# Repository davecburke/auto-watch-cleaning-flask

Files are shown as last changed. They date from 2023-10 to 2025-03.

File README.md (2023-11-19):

# auto-watch-cleaning-flask

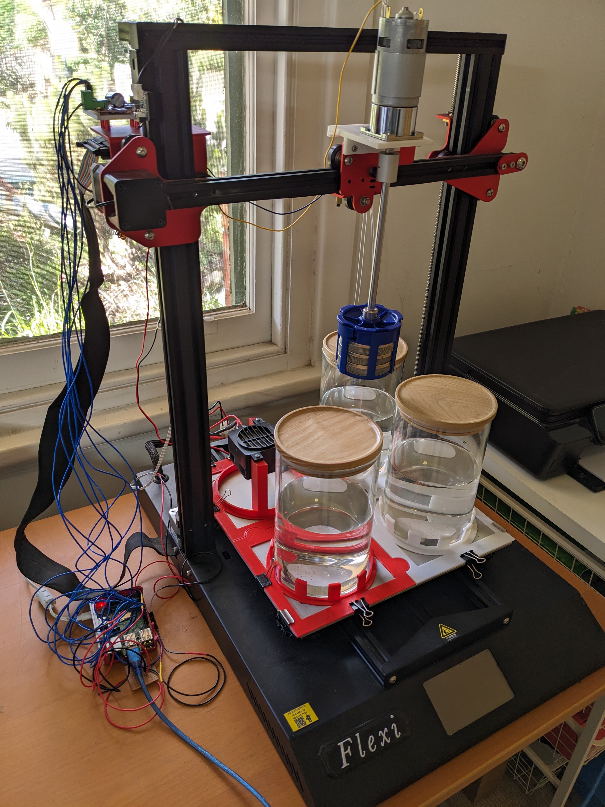
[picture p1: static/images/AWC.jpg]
AWC Auto Watch Cleaning Machine


Watch cleaning machines make the cleaning of mechanical watches both convenient and very effective but they can be expensive with most manual machines starting at around $1000 AUD and automatic machines starting at around $8,000 AUD. This is a big expense for a hobbiest like me.

It dawned on me that a 3D printer could be converted into a watch cleaning machine by replacing the hotend on the X axis with a spinning motor. How hard could it be, right!

## Specifications
- Fully automatic
- 1 x Cleaning Chamber
- 2 x Rinse Chamber
- 1 x Drying Chamber
NB: I've decided to make it easier for myself so I purchases the Elma SE Basket Complete and the Elma Basket Holder for RM/SE. You could of course rig up your own basket system on the cheap

## Features
The cleaning stage and the two rinse stages consist of two phases, the wash/rinse phase and the spin phase to expel liquid. The drying stage only has a spin phase.  All features are configured via a configuration file. These include:
- Setting the duration of each phase of the clean
- Setting the motor speed for each phase of the clean
- Setting the motor action for each phase of the clean. These are forward, backward and agitate (a user configured combination of forward and backward movements)

For detail of the full build, see my [instructable](https://www.instructables.com/3D-Printer-Conversion-to-Automatic-Watch-Cleaning-/)

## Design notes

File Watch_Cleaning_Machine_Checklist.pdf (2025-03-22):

## Watch Cleaning Machine Checklist

### Machine Cleaning Stages

Stage | Jar | Fluid | Action | RPM | Time | Notes
Cleaning | 1 | Shellite or Naphtha | Agitate + Spin (F/B) | 400-600 | 3-5 min | Removes oils & dirt
Rinse 1 | 2 | Clean Shellite | Slow Spin (F/B alt) | 400-600 | 2-3 min | Clears residual cleaner
Rinse 2 | 3 | Ultra-clean Shellite or
| | 99.9% IPA | Slow Spin (F/B alt) | 400-600 | 2-3 min | Final solvent rinse
Drying | - | - | Spin + Optional Heat | 800-1200 | 15-30 sec | No shellac-sensitive parts!

### Solvent Notes

- Shellite = Australian lighter fluid. Safe for delicate parts when used manually.
- 99.9% IPA = Optional final rinse. Avoid if unsure of purity.
- Avoid using water in this workflow - may damage shellac or cause rust.

### Manual Cleaning (Do Separately)

### - Pallet Fork & Balance Assembly: - Dip manually in Shellite (30-60 sec) - No brushing or ultrasonic - Blow-dry with air puffer - Avoid IPA and water

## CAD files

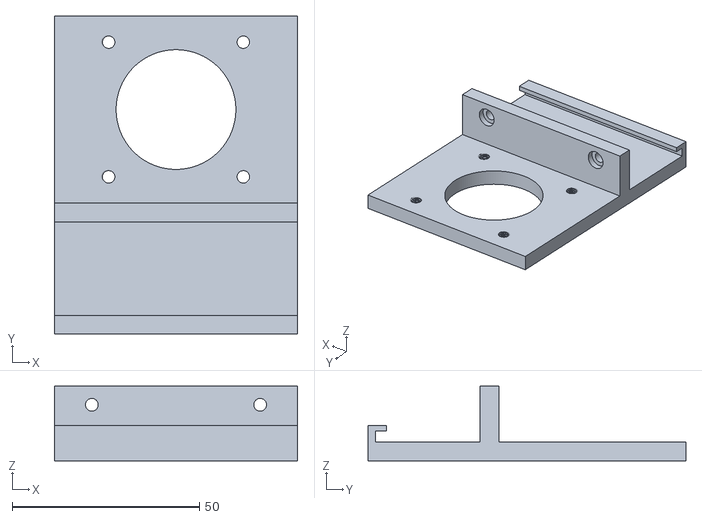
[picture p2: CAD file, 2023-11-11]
Freecad/WatchCleaning/Motor_Mount/Motor_Mount-Complete.stl
65.0 x 85.0 x 20.0

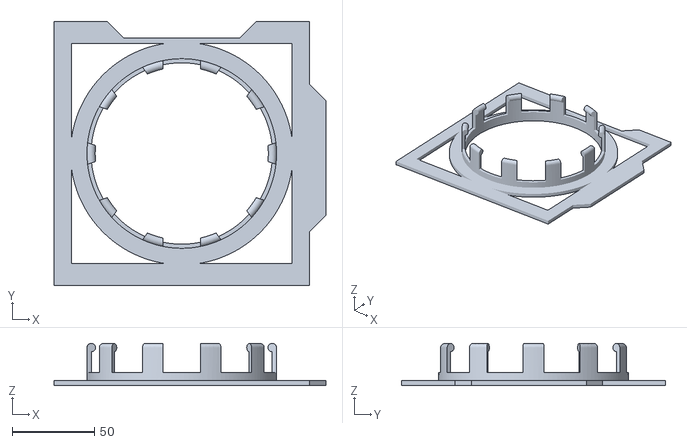
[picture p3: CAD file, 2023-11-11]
Freecad/WatchCleaning/Jar_Holders/Jar_Holders-Body.stl
165.0 x 160.0 x 25.5

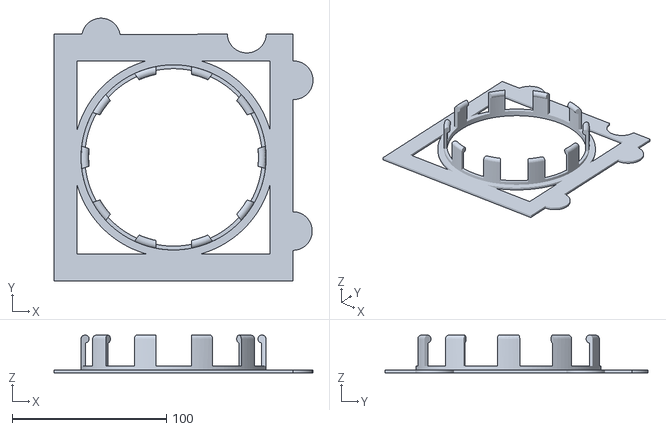
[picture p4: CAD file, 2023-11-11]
Freecad/WatchCleaning/Jar_Holders/Version2/JarHoldersV2_Split-Slice.FL.stl
167.9 x 170.2 x 24.5

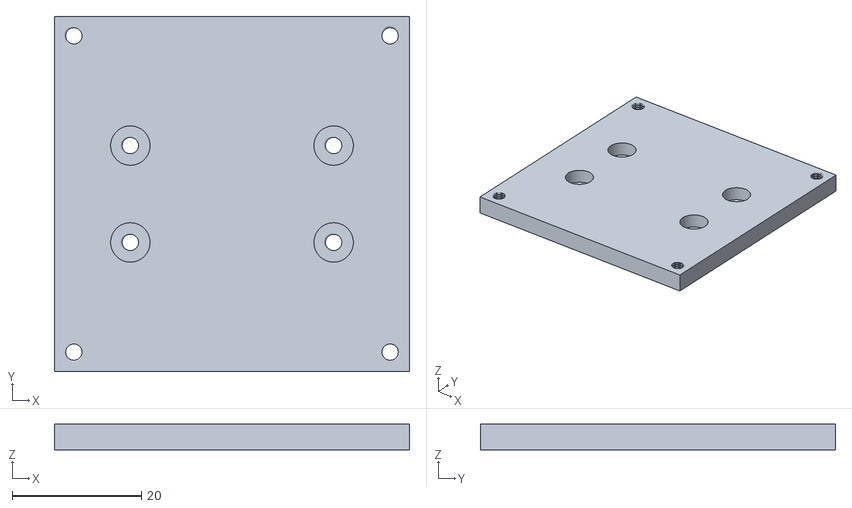
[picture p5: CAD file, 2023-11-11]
Freecad/WatchCleaning/Motor_Controller_Mount/Motor_Controller_Mount-Body2.stl
55.0 x 55.0 x 4.00

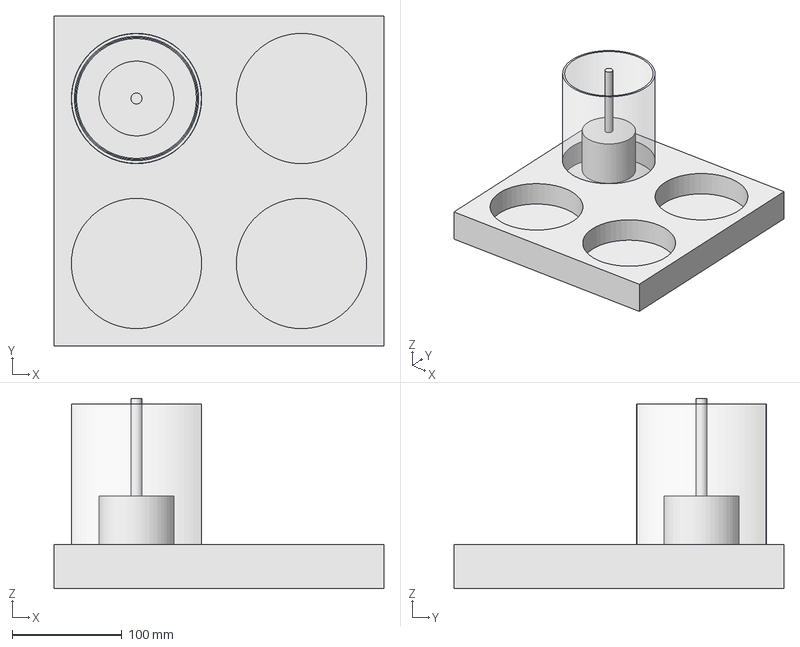
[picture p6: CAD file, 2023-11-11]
Freecad/WatchCleaning/WatchCleaning_v1.FCStd
300.0 x 300.0 x 173.0 mm
Jar
Basket
Base

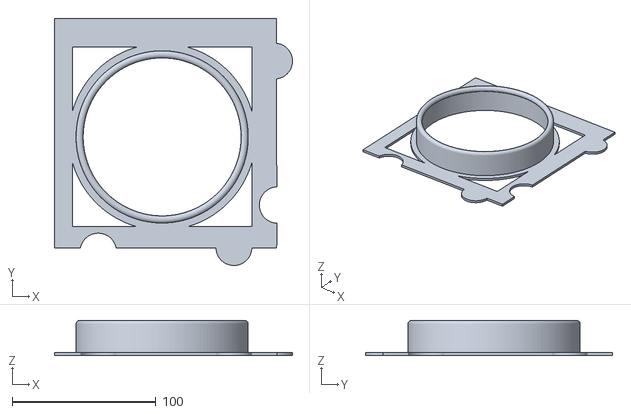
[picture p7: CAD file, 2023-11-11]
Freecad/WatchCleaning/Jar_Holders/Version2/JarHoldersV2_Split-Slice.BL.stl
165.8 x 172.1 x 24.5

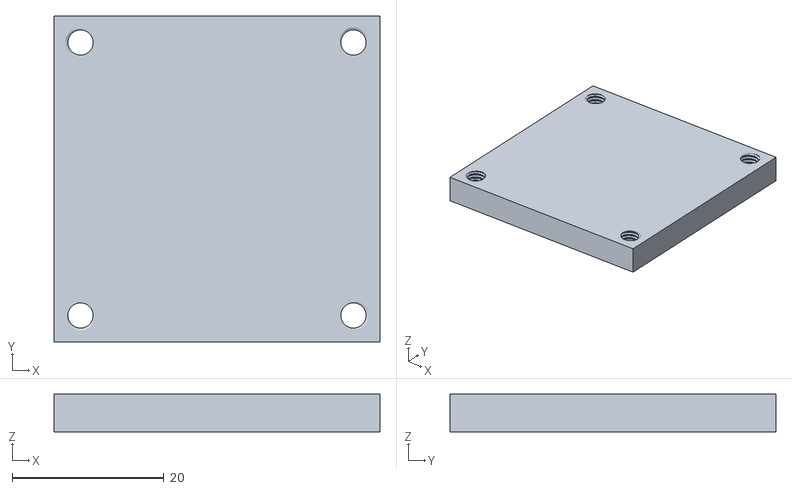
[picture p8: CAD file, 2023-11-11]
Freecad/WatchCleaning/Motor_Mount/Motor_Mount-Mount.stl
43.0 x 43.0 x 5.00

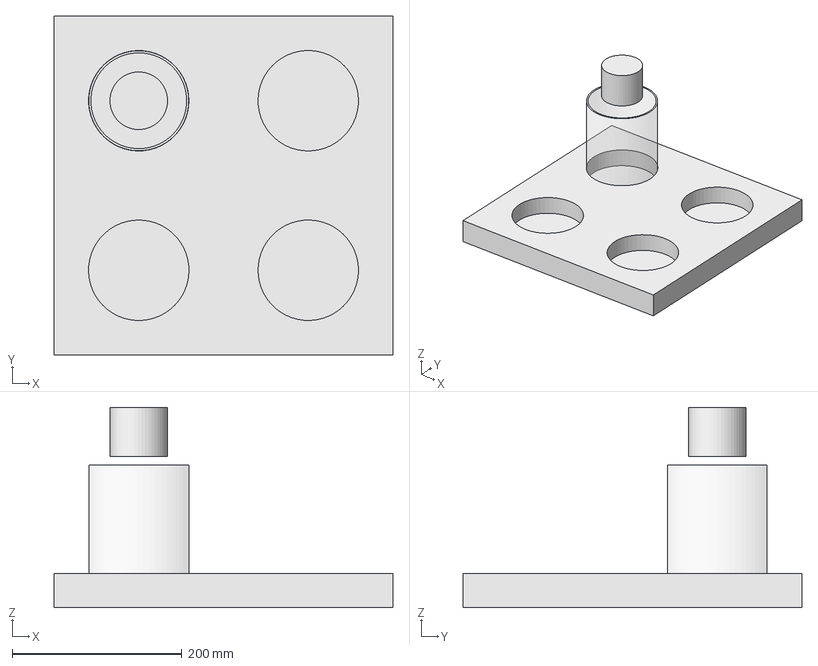
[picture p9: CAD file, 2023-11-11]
Freecad/WatchCleaning/WatchCleaning.FCStd
400.0 x 400.0 x 236.0 mm
Jar
Basket
Base

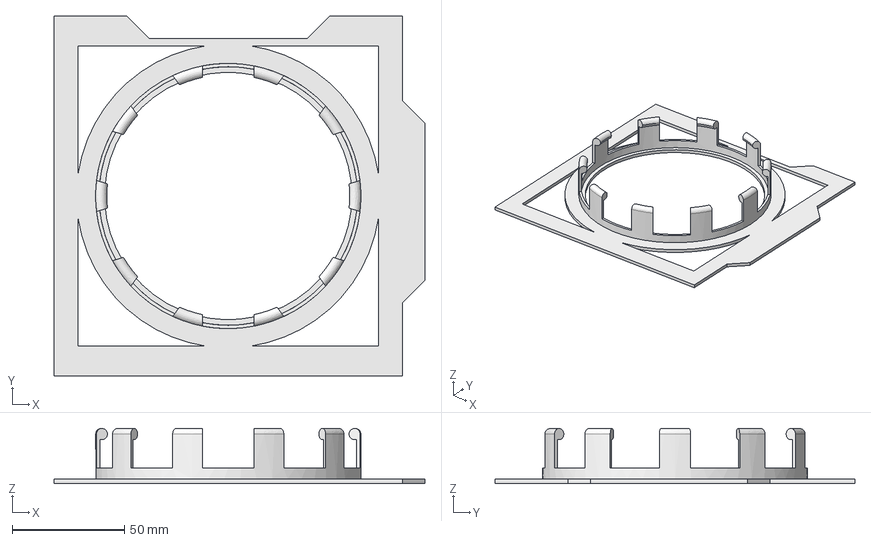
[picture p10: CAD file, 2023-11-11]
Freecad/WatchCleaning/Jar_Holders/Jar_Holders3.FCStd
165.0 x 160.0 x 24.5 mm

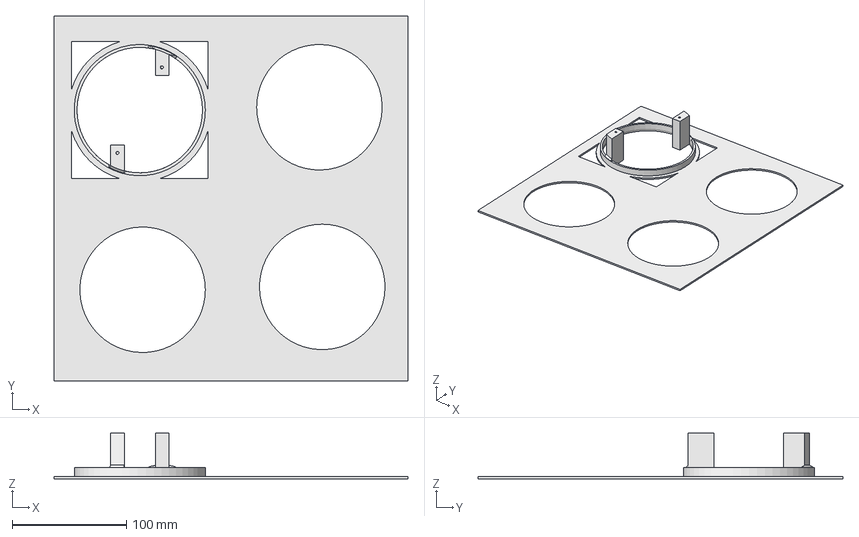
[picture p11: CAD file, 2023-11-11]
Freecad/WatchCleaning/Jar_Holders/Version2/JarHoldersV5_Heater_PreSplit.FCStd
310.0 x 320.0 x 40.0 mm

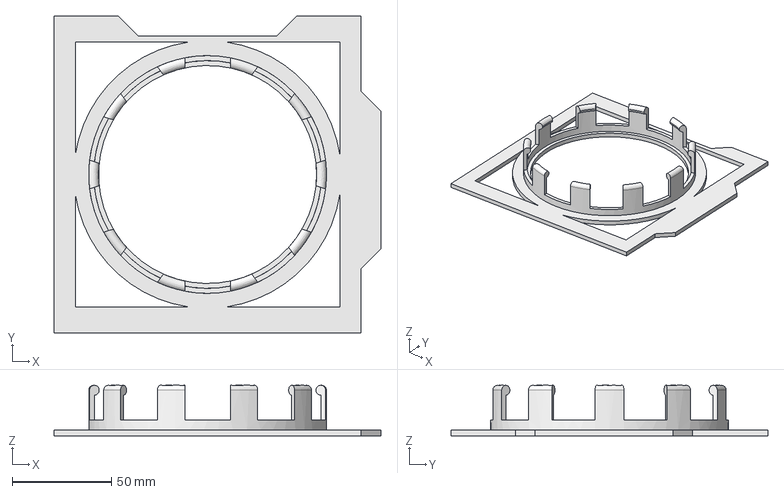
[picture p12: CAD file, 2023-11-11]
Freecad/WatchCleaning/Jar_Holders/Jar_Holders2.FCStd
165.0 x 160.0 x 25.5 mm

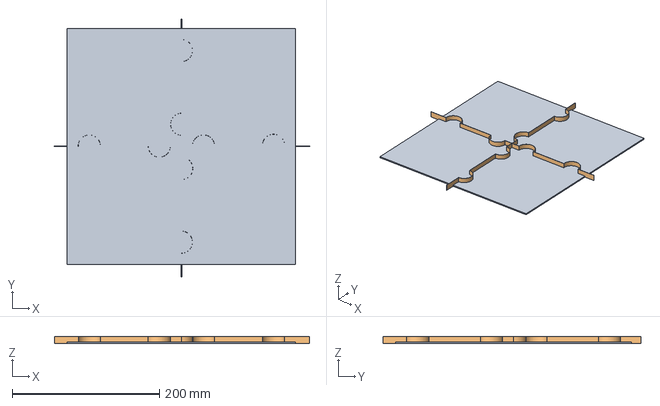
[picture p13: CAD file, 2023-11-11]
Freecad/WatchCleaning/Jar_Holders/Version2/JarHoldersV2_base.FCStd
346.0 x 350.0 x 10.0 mm
BuildPlate
Cutter

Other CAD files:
Freecad/WatchCleaning/Jar_Holders/Jar_Holders.FCStd
Freecad/WatchCleaning/Motor_Controller_Mount/Motor_Controller_Mount.FCStd
Freecad/WatchCleaning/Motor_Controller_Mount/Motor_Controller_Mount-Body.stl
Freecad/WatchCleaning/Motor_Mount/Motor_Mount.FCStd
Freecad/WatchCleaning/Motor_Controller_Mount/Motor_Controller_Mount-Body3.stl
Freecad/WatchCleaning/Jar_Holders/Jar_Holders2-Body.stl
Freecad/WatchCleaning/Jar_Holders/Jar_Holders3-Body.stl
Freecad/WatchCleaning/Jar_Holders/Version2/JarHoldersV2.FCStd
Freecad/WatchCleaning/Jar_Holders/Version2/JarHoldersV2_PreSplit.FCStd
Freecad/WatchCleaning/Jar_Holders/Version2/JarHoldersV2_Split-Slice.BR.stl
Freecad/WatchCleaning/Jar_Holders/Version2/JarHoldersV2_Split-Slice.FR.stl
Freecad/WatchCleaning/Jar_Holders/Version2/JarHoldersV2_Split.FCStd
Freecad/WatchCleaning/Jar_Holders/Version2/JarHoldersV6_Heater_PreSplit-BL.stl
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

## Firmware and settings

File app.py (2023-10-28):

from flask import Flask, render_template, request
# from flask_cors import CORS
import atexit
from config import Config 
from printer import Printer
from cleaning import Cleaning

app = Flask(__name__)
# CORS(app, resources={r'/*': {'origins': '*'}})
app_config = Config('app.config')
print(app_config.dry_cycle.dry.motor_setting.speed)
app_printer = Printer();
app_cleaning = Cleaning()
def startCleaningProcess():
    if app_printer.prepare_printer():
        app_cleaning.clean()

def restartFirware():
    return app_printer.app_moonraker_util.firmware_restart()

def homePrinter(): 
    return app_printer.home_printer()
          
    
@app.route("/", methods=['GET', 'POST'])
def index():
    templateData = {}
    cleaning_status = 'Off'
    firmware_restart_status = ''
    firmware_state = ''
    firmware_message = ''
    homing_state = ''
    if request.method == 'POST':
        if request.form.get('start') == 'Start Cleaning':
            cleaning_status = 'Start'
            startCleaningProcess()
        if request.form.get('restart_firmware') == 'Restart Firmware':
            res = restartFirware();
            print(res)
            firmware_restart_status = 'Starting'
            while True:
                react_dict = app_printer.app_moonraker_util.server_get("/printer/info")
                if('result' in react_dict):
                    break
        if request.form.get('home') == 'Home':
            homing_state = 'Homing'
            while True:
                react_dict = homePrinter()
                if(app_printer.app_moonraker_util.is_printer_homed):
                    break
    react_dict = app_printer.app_moonraker_util.server_get("/printer/info")
    if('result' in react_dict):
        firmware_state = react_dict['result']['state']
        firmware_message = react_dict['result']['state_message']

    if(app_printer.app_moonraker_util.is_printer_homed):
        homing_state = 'Homed'
    else: 
        homing_state = 'Not Homed'        
    templateData = {'firmware_state': firmware_state, 'firmware_message': firmware_message, 'cleaning_status': cleaning_status, 'restart_status': firmware_restart_status, 'homing_state': homing_state}
    print(templateData)
    return render_template('index.html', **templateData)

def exit_handler():
    app_cleaning.app_motor.clean_up()
atexit.register(exit_handler) 

if __name__ == '__main__':
    app.run(host='0.0.0.0')

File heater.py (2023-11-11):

import RPi.GPIO as GPIO
class Heater():
    def __init__(self, in1, in2, en, element):
        print(in1)
        print(in2)
        print(en)
        self.in1 = in1;
        self.in2 = in2;
        self.en = en;
        self.element = element
        GPIO.setmode(GPIO.BOARD)
        GPIO.setup(in1, GPIO.OUT)
        GPIO.setup(in2, GPIO.OUT)
        GPIO.setup(en, GPIO.OUT)
        GPIO.setup(element, GPIO.OUT)
        # self.pi_pwm = GPIO.PWM(en,1000)
        # self.pi_pwm.start(0)
    
    def heater_on(self):
        print('heater on')
        print(self.in1)
        print(self.en)
        # GPIO.output(self.in1, True)
        # GPIO.output(self.in2, False)
        # GPIO.output(self.en, True)
        GPIO.output(self.element, True)

    def heater_off(self):
        print('heater off')
        # GPIO.output(self.in1, False)
        # GPIO.output(self.in2, False)
        # GPIO.output(self.en, False)
        GPIO.output(self.element, False)

    def fan_on(self):
        print('fan on')
        print(self.in1)
        print(self.en)
        GPIO.output(self.in1, True)
        GPIO.output(self.in2, False)
        GPIO.output(self.en, True)
        # GPIO.output(self.element, True)

    def fan_off(self):
        print('fan off')
        GPIO.output(self.in1, False)
        GPIO.output(self.in2, False)
        GPIO.output(self.en, False)
        # GPIO.output(self.element, False)    

    def clean_up(self):
        print('clean up - motor')
        GPIO.cleanup()        

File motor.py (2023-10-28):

import RPi.GPIO as GPIO
import time
class Motor():
    def __init__(self, in1, in2, en):
        self.in1 = in1;
        self.in2 = in2;
        self.en = en;
        GPIO.setmode(GPIO.BOARD)
        GPIO.setup(in1, GPIO.OUT)
        GPIO.setup(in2, GPIO.OUT)
        GPIO.setup(en, GPIO.OUT)
        self.pi_pwm = GPIO.PWM(en,1000)
        self.pi_pwm.start(0)
    
    def forward(self, speed):
        print('forward')
        GPIO.output(self.in1, True)
        GPIO.output(self.in2, False)
        for x in range(0, int(speed), 1):
            self.pi_pwm.ChangeDutyCycle(x)
            time.sleep(1/speed)

    def backward(self, speed):
        print('backward')
        GPIO.output(self.in1, False)
        GPIO.output(self.in2, True)
        for x in range(0, int(speed), 1):
            self.pi_pwm.ChangeDutyCycle(x)
            time.sleep(1/speed)

    def brake(self, speed):
        print('brake')
        for x in range(int(speed), 0, -1):
            self.pi_pwm.ChangeDutyCycle(x)
            time.sleep(1/speed)
        GPIO.output(self.in1, False)
        GPIO.output(self.in2, False)

    def clean_up(self):
        print('clean up')
        self.pi_pwm.stop()
        GPIO.cleanup()    

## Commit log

2023-10-28 Added heater and ramp up/down for motor
2023-11-11 Added Freecad files
    [JarHoldersV2.FCStd, JarHoldersV2_PreSplit.FCStd, JarHoldersV2_Split-Slice.BL.stl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]
2023-11-11 Added heater code
2025-03-14 Created test app for the motor
2025-03-14 Updated motor speeds and recepticle placement
